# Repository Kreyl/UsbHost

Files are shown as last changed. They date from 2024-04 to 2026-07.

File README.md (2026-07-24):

# UsbHost
PCB with MCU &amp; CC1101, with USB connector

This project is for manupulating Ostranna devices from PC using radio
This branch is for Magic Stick project. There are two devices in system, host and wand https://github.com/Kreyl/MagicStick.
Wand sends raw data from IMU to host and host may send commands to wand.

Protocol descrideb here (in Russian) https://docs.google.com/document/d/1Enq7OxXN71MnZqI4T44DpILLiYlTNmURxSFmcvyZTgg/edit
List of commands in Russian https://docs.google.com/document/d/1xTNT9nXQbrqk0kijIyspimRIQRoJOtMbkZyYuiGS3eA/edit#heading=h.siqy2t4hsq6f
USB2Radio devices displays itself as virtual COM-port, you may user Terminal app to send commands or send commands from your code to serial port object. 

Archived branches are available here https://github.com/Kreyl/UsbHost/tags

We also have python module to work with USB2Radio  (in python folder). 

<details>
  <summary>Commands list:</summary> 

*get_port_list() function returns list of available comports as ['COM3', 'COM5', 'COM20' ...];

*get_device_port function returns first found port with Ostranna device (answer 'Ack 0' to 'Ping\r\n') as 'COM4';

*get_all_device_ports() returns list of comports with Ostranna devices connected 
                        (answer 'Ack 0' to 'Ping\r\n') as ['COM4', ...];

*open_port(port_id: str) takes comport as str parameter (open_port('COM4') and returns open port or None;

*send command(ser, command, parameters) send command with parameters to ser port, returns send status
              ("ok", "Bad data", "Unknown command" or "No device port") ;

*send query(ser, command, parameters) send query with parameters to ser port and returns answer;

*close_port(ser) gets result of open_port(port_id) as parameter and closes it .
</details>

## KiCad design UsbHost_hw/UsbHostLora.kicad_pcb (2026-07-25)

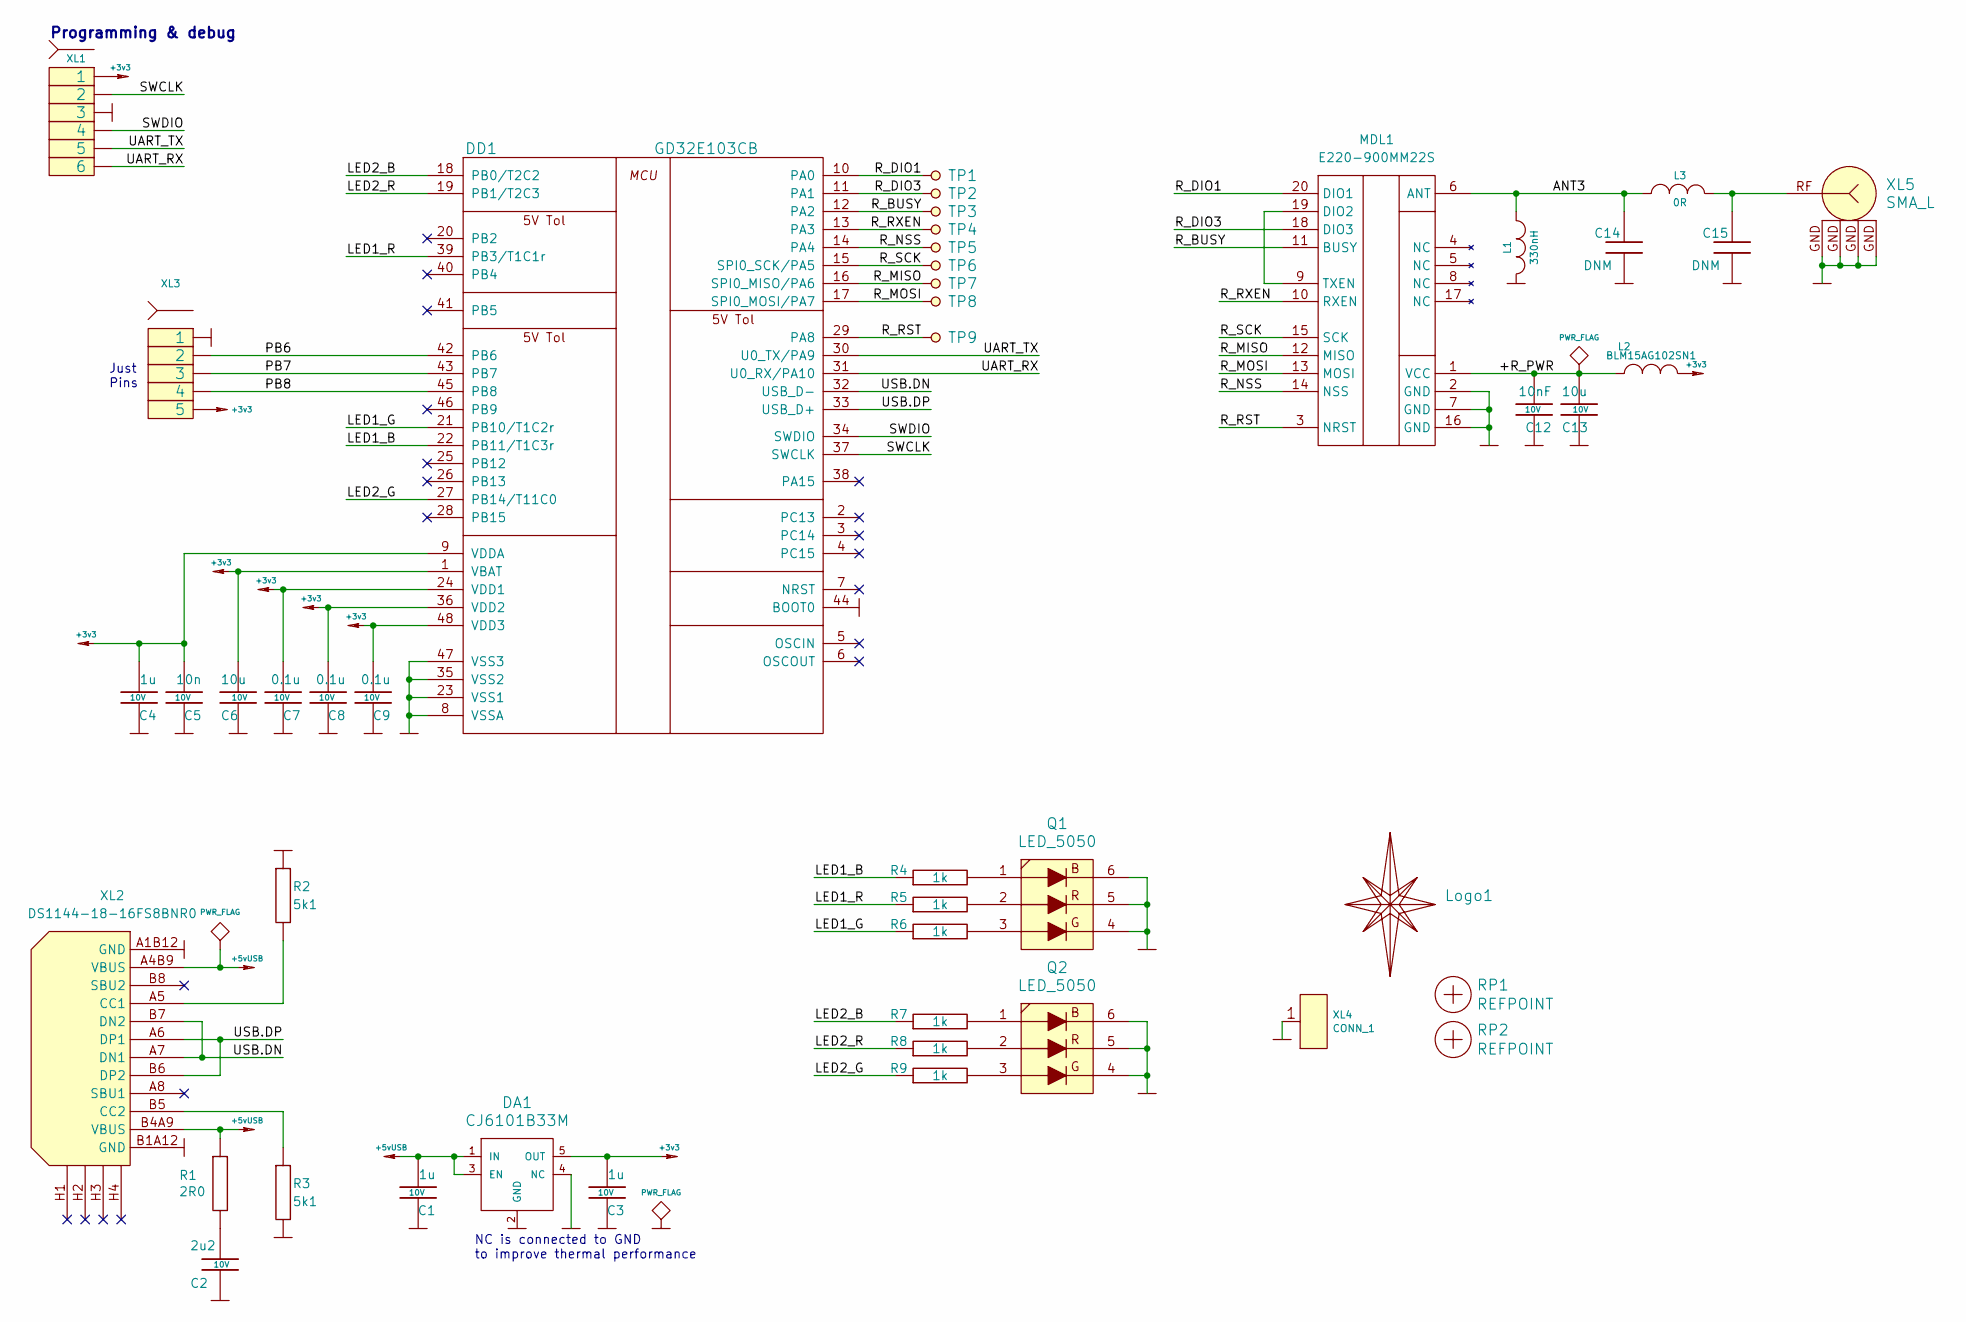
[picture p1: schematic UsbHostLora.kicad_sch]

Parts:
C1, C3, C4: 1u; CAP_0603_Silks; Tolerance 20%; Voltage 10V
C2: 2u2; CAP_0603_Silks; Tolerance 20%; Voltage 10V
C5: 10n; CAP_0603_Silks; Tolerance 20%; Voltage 10V
C6, C13: 10u; CAP_0603_Silks; Tolerance 20%; Voltage 10V
C7, C8, C9: 0.1u; CAP_0603_Silks; Tolerance 20%; Voltage 10V
C12: 10nF; CAP_0603_Silks; Tolerance 20%; Voltage 10V
C14, C15: DNM; CAP_0402_Silks; Tolerance 20%; Voltage 10V
DA1: CJ6101B33M; SOT23-5
DD1: GD32E103CB; LQFP48
L1: 330nH; IND_0402; Tolerance 20%
L2: BLM15AG102SN1; IND_0402; Tolerance 20%
L3: 0R; IND_0402; Tolerance 20%
Logo1: Logo; Ostranna_12d7_10d1
MDL1: E220-900MM22S
Q1, Q2: LED_5050
R1: 2R0; RES_0603_RefFab; Tolerance 1%
R2, R3: 5k1; RES_0603_RefFab; Tolerance 1%
R4, R5, R6, R7, R8, R9: 1k; RES_0603_RefFab; Tolerance 1%
RP1, RP2: REFPOINT; REF_POINT_1MM
TP1, TP2, TP3, TP4, TP5, TP6, TP7, TP8, TP9: TESTPOINT; TESTPOINT_1MM
XL1: SOCKET_6; PLS-6_LOCK
XL2: DS1144-18-16FS8BNR0; USBC_10PF-074_1
XL3: SOCKET_5; PLS-5
XL4: CONN_1; OSCIL_GND
XL5: SMA_L; SMA_R

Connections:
+3v3: C3.1, C4.1, C5.1, C6.1, C7.1, C8.1, C9.1, DA1.5 (OUT), DD1.1 (VBAT), DD1.9 (VDDA), DD1.24 (VDD1), DD1.36 (VDD2), DD1.48 (VDD3), L2.1, XL1.1, XL3.5
+5vUSB: C1.1, DA1.1 (IN), DA1.3 (EN), R1.1, XL2.A4B9 (VBUS), XL2.B4A9 (VBUS)
/+R_PWR: C12.1, C13.1, L2.2, MDL1.1 (VCC)
/ANT3: C14.1, L1.2, L3.2, MDL1.6 (ANT)
/LED1_B: DD1.22 (PB11/T1C3r), R4.1
/LED1_G: DD1.21 (PB10/T1C2r), R6.1
/LED1_R: DD1.39 (PB3/T1C1r), R5.1
/LED2_B: DD1.18 (PB0/T2C2), R7.1
/LED2_G: DD1.27 (PB14/T11C0), R9.1
/LED2_R: DD1.19 (PB1/T2C3), R8.1
/PB6: DD1.42 (PB6), XL3.2
/PB7: DD1.43 (PB7), XL3.3
/PB8: DD1.45 (PB8), XL3.4
/R_BUSY: DD1.12 (PA2), MDL1.11 (BUSY), TP3.1
/R_DIO1: DD1.10 (PA0), MDL1.20 (DIO1), TP1.1
/R_DIO3: DD1.11 (PA1), MDL1.18 (DIO3), TP2.1
/R_MISO: DD1.16 (SPI0_MISO/PA6), MDL1.12 (MISO), TP7.1
/R_MOSI: DD1.17 (SPI0_MOSI/PA7), MDL1.13 (MOSI), TP8.1
/R_NSS: DD1.14 (PA4), MDL1.14 (NSS), TP5.1
/R_RST: DD1.29 (PA8), MDL1.3 (NRST), TP9.1
/R_RXEN: DD1.13 (PA3), MDL1.10 (RXEN), TP4.1
/R_SCK: DD1.15 (SPI0_SCK/PA5), MDL1.15 (SCK), TP6.1
/SWCLK: DD1.37 (SWCLK), XL1.2
/SWDIO: DD1.34 (SWDIO), XL1.4
/UART_RX: DD1.31 (U0_RX/PA10), XL1.6
/UART_TX: DD1.30 (U0_TX/PA9), XL1.5
/USB.DN: DD1.32 (USB_D-), XL2.A7 (DN1), XL2.B7 (DN2)
/USB.DP: DD1.33 (USB_D+), XL2.A6 (DP1), XL2.B6 (DP2)
GND: C1.2, C2.2, C3.2, C4.2, C5.2, C6.2, C7.2, C8.2, C9.2, C12.2, C13.2, C14.2, C15.2, DA1.2 (GND), DA1.4 (NC), DD1.8 (VSSA), DD1.23 (VSS1), DD1.35 (VSS2), DD1.44 (BOOT0), DD1.47 (VSS3), L1.1, MDL1.2 (GND), MDL1.7 (GND), MDL1.16 (GND), Q1.4 (B), Q1.5 (G), Q1.6, Q2.4 (B), Q2.5 (G), Q2.6, R2.1, R3.2, XL1.3, XL2.A1B12 (GND), XL2.B1A12 (GND), XL3.1, XL4.1 (P1_1), XL5.GND
unnamed: C2.1, R1.2
unnamed: C15.1, L3.1, XL5.RF
unnamed: MDL1.9 (TXEN), MDL1.19 (DIO2)
unnamed: Q1.1, R4.2
unnamed: Q1.2, R5.2
unnamed: Q1.3, R6.2
unnamed: Q2.1, R7.2
unnamed: Q2.2, R8.2
unnamed: Q2.3, R9.2
unnamed: R2.2, XL2.A5 (CC1)
unnamed: R3.1, XL2.B5 (CC2)

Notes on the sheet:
Just Pins
NC is connected to GND to improve thermal performance
Programming & debug

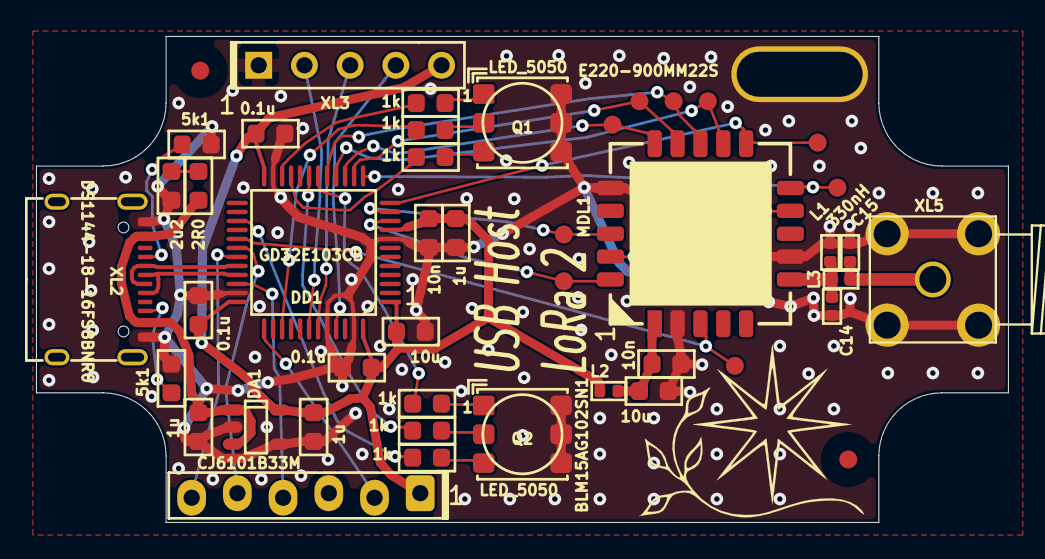
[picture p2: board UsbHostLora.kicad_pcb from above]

Board: 2 copper layers, 54.0 x 27.0 mm, 47 parts (0 on the bottom side), 40 nets.

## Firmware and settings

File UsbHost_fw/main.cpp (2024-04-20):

#include "uart.h"
#include "ch.h"
#include "hal.h"
#include "MsgQ.h"
#include "shell.h"
#include "kl_lib.h"
#include "Sequences.h"
#include "led.h"
#include "color.h"
#include "usb_cdc.h"
#include "Lora.h"

#if 1 // ======================== Variables and defines ========================
// Forever
EvtMsgQ_t<EvtMsg_t, MAIN_EVT_Q_LEN> EvtQMain;
static const UartParams_t CmdUartParams(115200, CMD_UART_PARAMS);
CmdUart_t Uart{CmdUartParams};
void OnCmd(Shell_t *PShell);
void ITask();

LedRGB_t Led { LED_R_PIN, LED_G_PIN, LED_B_PIN, 1000 };

// [2; 20]
#define TX_PWR_dBm      11
// bwLora125kHz, bwLora250kHz, bwLora500kHz
#define LORA_BW         bwLora250kHz
// sprfact64chipsPersym, sprfact128chipsPersym, sprfact256chipsPersym, sprfact512chipsPersym,
// sprfact1024chipsPersym, sprfact2048chipsPersym, sprfact4096chipsPersym
#define LORA_SPREADRFCT sprfact1024chipsPersym
// coderate4s5, coderate4s6, coderate4s7, coderate4s8
#define LORA_CODERATE   coderate4s8
#endif


void main(void) {
    // ==== Init Clock system ====
    Clk.EnablePrefetch();
    Clk.SetupFlashLatency(48000000);
    Clk.SetupBusDividers(ahbDiv1, apbDiv1);
    Clk.SwitchTo(csHSI48);
    Clk.UpdateFreqValues();

    // === Init OS ===
    halInit();
    chSysInit();
    EvtQMain.Init();

    // ==== Init hardware ====
    Uart.Init();
    Printf("\r%S %S\r", APP_NAME, XSTRINGIFY(BUILD_TIME));
    Clk.PrintFreqs();

    Led.Init();
    Led.StartOrRestart(lsqStart);

    Lora.Init();
    Lora.SetChannel(868000000);
    Lora.SetupRxConfigLora(LORA_BW, LORA_SPREADRFCT, LORA_CODERATE, hdrmodeExplicit, 64);
    Lora.SetupTxConfigLora(TX_PWR_dBm, LORA_BW, LORA_SPREADRFCT, LORA_CODERATE, hdrmodeExplicit);

    UsbCDC.Init();
    Clk.EnableCRS();
    Clk.SelectUSBClock_HSI48();
    UsbCDC.Connect();

    ITask(); // Main cycle
}

__noreturn
void ITask() {
    while(true) {
        EvtMsg_t Msg = EvtQMain.Fetch(TIME_INFINITE);
        switch(Msg.ID) {
            case evtIdShellCmdRcvd:
                while(((CmdUart_t*)Msg.Ptr)->TryParseRxBuff() == retvOk) OnCmd((Shell_t*)((CmdUart_t*)Msg.Ptr));
                break;

#if 1       // ======= USB =======
            case evtIdUsbCmdRcvd:
                Led.StartOrRestart(lsqUSBCmd);
                OnCmd((Shell_t*)&UsbCDC);
                UsbCDC.SignalCmdProcessed();
                break;

            case evtIdUsbConnect:
                Printf("USB connect\r");
                Clk.EnableCRS();
                Clk.SelectUSBClock_HSI48();
                UsbCDC.Connect();
                break;

            case evtIdUsbDisconnect: {
                UsbCDC.Disconnect();
                Clk.DisableCRS();
                Printf("USB disconnect\r");
            } break;

            case evtIdUsbReady:
                Printf("USB ready\r");
                Led.StartOrRestart(lsqUsbReady);
                break;
#endif

            default: break;
        } // switch
    } // while true
}

const char* strBW[3] = {"125kHz", "250kHz", "500kHz"};
SXLoraBW_t bw[3] = {bwLora125kHz, bwLora250kHz, bwLora500kHz};


const char* strSF[7] = {
        "64cps", "128cps", "256cps", "512cps", "1024cps", "2048cps", "4096cps"
};
SXSpreadingFactor_t sf[7] = {sprfact64chipsPersym, sprfact128chipsPersym, sprfact256chipsPersym,
        sprfact512chipsPersym, sprfact1024chipsPersym, sprfact2048chipsPersym, sprfact4096chipsPersym
};

const char* strCR[4] = {
        "4s5", "4s6", "4s7", "4s8"
};

SXCodingRate_t CR[4] = {
        coderate4s5, coderate4s6, coderate4s7, coderate4s8
};

#if 1 // =========================== Pkt_t =====================================
#pragma pack(push, 1)
union rPkt_t {
    struct {
        uint32_t reply;
        uint32_t salt_reply;
    };
    struct {
        uint8_t cmd;
        union {
            struct { int16_t grif, slyze, rave, huff; };
            struct {
                uint16_t year;
                uint8_t month, day, hours, minutes;
            };
        };
    };
};
#pragma pack(pop)

static const uint8_t kcmd_set_shown = 1;
static const uint8_t kcmd_set_hidden = 0;
static const uint8_t kcmd_set_time = 7;

#define RPKT_SALT   0xF1170511 // Fly to sly
#define RPKT_LEN    sizeof(rPkt_t)
rPkt_t rpkt;
static uint8_t rxbuf[LORA_FIFO_SZ];
#endif

void TryToTxRpkt(Shell_t *PShell) {
    for(uint8_t i=0; i<4; i++) { // Try several times
        Lora.SetupTxConfigLora(TX_PWR_dBm, LORA_BW, LORA_SPREADRFCT, LORA_CODERATE, hdrmodeExplicit);
        Lora.TransmitByLora((uint8_t*)&rpkt, RPKT_LEN);
        uint8_t len = LORA_FIFO_SZ;
        Lora.SetupRxConfigLora(LORA_BW, LORA_SPREADRFCT, LORA_CODERATE, hdrmodeExplicit, 64);
        uint8_t Rslt = Lora.ReceiveByLora(rxbuf, &len, 270);
        rPkt_t *pkt_rx = (rPkt_t*)rxbuf;
        if(Rslt == retvOk and len == RPKT_LEN and pkt_rx->salt_reply == RPKT_SALT) {
            PShell->Print("Result: Ok  SNR: %d; RSSI: %d\r\n", Lora.RxParams.SNR, Lora.RxParams.RSSI);
            return;
//                PShell->Print("Rply: %X; SNR: %d; RSSI: %d\r", PktRx->Reply, Lora.RxParams.SNR, Lora.RxParams.RSSI);
        }
        else if(Rslt == retvCRCError) PShell->Print("CRCErr\r\n");
        else PShell->Print("%u: Timeout\r\n", i);
        chThdSleepMilliseconds(180);
    } // for
    PShell->Print("Result: Fail\r\n");
}


#if 1 // ======================= Command processing ============================
void OnCmd(Shell_t *PShell) {
    Cmd_t *PCmd = &PShell->Cmd;
//    Printf("%S\r", PCmd->Name);
    // Handle command
    if(PCmd->NameIs("Ping")) PShell->Ok();
    else if(PCmd->NameIs("Version")) PShell->Print("Version: %S %S\r", APP_NAME, XSTRINGIFY(BUILD_TIME));
    else if(PCmd->NameIs("mem")) PrintMemoryInfo();

    else if(PCmd->NameIs("TX")) {
        uint8_t Pwr, BWIndx, SFIndx, CRIndx;
        uint8_t FBuf[LORA_FIFO_SZ];
        if(PCmd->GetParams<uint8_t>(4, &Pwr, &BWIndx, &SFIndx, &CRIndx) == retvOk) {
            Lora.SetupTxConfigLora(Pwr, bw[BWIndx], sf[SFIndx], CR[CRIndx], hdrmodeExplicit);
            uint8_t b, Cnt=0;
            while(PCmd->GetNext<uint8_t>(&b) == retvOk) {
                FBuf[Cnt++] = b;
                if(Cnt == LORA_FIFO_SZ) break;
            }
            if(Cnt) {
                PShell->Print("Pwr=%u; Len=%u; %S; %S; %S; Dur=%u\r\n",
                        Pwr, Cnt, strBW[BWIndx], strSF[SFIndx], strCR[CRIndx],
                        Lora.TransmitByLora(FBuf, Cnt));
            }
            else PShell->CmdError();
        }
        else PShell->CmdError();
    }

    else if(PCmd->NameIs("Set")) {
        int32_t arr[5];
        if(PCmd->GetArray(arr, 5) == retvOk) {
            rpkt.grif  = arr[0];
            rpkt.slyze = arr[1];
            rpkt.rave  = arr[2];
            rpkt.huff  = arr[3];
            rpkt.cmd = arr[4]? kcmd_set_shown : kcmd_set_hidden;
            TryToTxRpkt(PShell);
        }
        else PShell->BadParam();
    }

    else if(PCmd->NameIs("SetTime")) {
        uint16_t arr[5];
        if(PCmd->GetArray(arr, 5) == retvOk) {
            rpkt.cmd = kcmd_set_time;
            rpkt.year    = arr[0];
            rpkt.month   = arr[1];
            rpkt.day     = arr[2];
            rpkt.hours   = arr[3];
            rpkt.minutes = arr[4];
            TryToTxRpkt(PShell);
        }
        else PShell->BadParam();
    }

    // ==== Lora params ====
    else if(PCmd->NameIs("SetParams")) {
        uint8_t Pwr, BWIndx, SFIndx, CRIndx;
        if(PCmd->GetParams<uint8_t>(4, &Pwr, &BWIndx, &SFIndx, &CRIndx) == retvOk) {
            Lora.SetupTxConfigLora(Pwr, bw[BWIndx], sf[SFIndx], CR[CRIndx], hdrmodeExplicit);
            Lora.SetupRxConfigLora(bw[BWIndx], sf[SFIndx], CR[CRIndx], hdrmodeExplicit, 64);
            PShell->Print("Pwr=%u; %S; %S; %S\r\n", Pwr, strBW[BWIndx], strSF[SFIndx], strCR[CRIndx]);
        }
        else PShell->CmdError();
    }

    else if(PCmd->NameIs("Regs")) Lora.PrintRegs();
    else if(PCmd->NameIs("Sta")) Lora.PrintState();

    else if(PCmd->NameIs("help")) {
        PShell->Print( "SetTime <Year> <Month> <Day> <H> <M>\r"
                "Set <Grif> <Slyze> <Rave> <Huff> <show_points> - set points\r"
        );
    }

    else PShell->CmdUnknown();
}
#endif

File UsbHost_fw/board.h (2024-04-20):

/*
 * board.h
 *
 *  Created on: 01.02.2017
 *      Author: Kreyl
 */

#ifndef BOARD_H__
#define BOARD_H__

// ==== General ====
#define BOARD_NAME          "UsbHostLora"
#define APP_NAME            "UsbHostFlasks"

// MCU type as defined in the ST header.
#define STM32F072xB     // no matter, 8 or B

// Freq of external crystal if any. Leave it here even if not used.
#define CRYSTAL_FREQ_HZ         12000000

// Ch timer
#define STM32_ST_IRQ_PRIORITY   2
#define STM32_ST_USE_TIMER      2
#define SYS_TIM_CLK             (Clk.APBFreqHz)

#define SIMPLESENSORS_ENABLED   FALSE
#define BUTTONS_ENABLED         FALSE
#define ADC_REQUIRED            FALSE
#define I2C1_ENABLED            FALSE
#define I2C_USE_SEMAPHORE       FALSE

#if 1 // ========================== GPIO =======================================
// PortMinTim_t: GPIO, Pin, Tim, TimChnl, invInverted, omPushPull, TopValue

// UART
#define UART_GPIO       GPIOA
#define UART_TX_PIN     9
#define UART_RX_PIN     10

// USB
#define USB_DM          GPIOA, 11
#define USB_DP          GPIOA, 12

// LED
#define LED_R_PIN       { GPIOC, 6, TIM3, 1, invNotInverted, omPushPull, 255 }
#define LED_G_PIN       { GPIOC, 8, TIM3, 2, invNotInverted, omPushPull, 255 }
#define LED_B_PIN       { GPIOC, 7, TIM3, 3, invNotInverted, omPushPull, 255 }

// ==== Lora ====
#define SX_SPI          SPI1
#define SX_SCK          GPIOA,  5, omPushPull, pudNone, AF0
#define SX_MISO         GPIOA,  6, omPushPull, pudNone, AF0
#define SX_MOSI         GPIOA,  7, omPushPull, pudNone, AF0
#define SX_NSS          GPIOA, 4
#define SX_NRESET       GPIOC, 3
#define SX_DIO0_GPIO    GPIOA
#define SX_DIO0_PIN     0
#define SX_DIO1_GPIO    GPIOA
#define SX_DIO1_PIN     1
#define SX_DIO2_GPIO    GPIOA
#define SX_DIO2_PIN     2
#define SX_DIO3_GPIO    GPIOA
#define SX_DIO3_PIN     3
#define SX_DIO4_GPIO    GPIOC
#define SX_DIO4_PIN     4
#define SX_DIO5_GPIO    GPIOC
#define SX_DIO5_PIN     5

#endif // GPIO

#if 1 // ========================== USB ========================================
#define USBDrv          USBD1   // USB driver to use

// CRS
#define CRS_PRESCALER   RCC_CRS_SYNC_DIV1
#define CRS_SOURCE      RCC_CRS_SYNC_SOURCE_USB
#define CRS_POLARITY    RCC_CRS_SYNC_POLARITY_RISING
#define CRS_RELOAD_VAL  ((48000000 / 1000) - 1) // Ftarget / Fsync - 1
#define CRS_ERROR_LIMIT 34
#define HSI48_CALIBRATN 32
#endif

#if 1 // =========================== DMA =======================================
#define STM32_DMA_REQUIRED  TRUE
// ==== Uart ====
#define UART_DMA_TX_MODE(Chnl) (STM32_DMA_CR_CHSEL(Chnl) | DMA_PRIORITY_LOW | STM32_DMA_CR_MSIZE_BYTE | STM32_DMA_CR_PSIZE_BYTE | STM32_DMA_CR_MINC | STM32_DMA_CR_DIR_M2P | STM32_DMA_CR_TCIE)
#define UART_DMA_RX_MODE(Chnl) (STM32_DMA_CR_CHSEL(Chnl) | DMA_PRIORITY_MEDIUM | STM32_DMA_CR_MSIZE_BYTE | STM32_DMA_CR_PSIZE_BYTE | STM32_DMA_CR_MINC | STM32_DMA_CR_DIR_P2M | STM32_DMA_CR_CIRC)
#define UART_DMA_TX     STM32_DMA_STREAM_ID(1, 2)
#define UART_DMA_RX     STM32_DMA_STREAM_ID(1, 3)
#define UART_DMA_CHNL   0   // Dummy

#endif // DMA

#if 1 // ========================== USART ======================================
#define PRINTF_FLOAT_EN FALSE
#define UART_TXBUF_SZ   2048
#define UART_RXBUF_SZ   1024
#define CMD_BUF_SZ      256

#define CMD_UART        USART1


#define CMD_UART_PARAMS \
    CMD_UART, UART_GPIO, UART_TX_PIN, UART_GPIO, UART_RX_PIN, \
    UART_DMA_TX, UART_DMA_RX, UART_DMA_TX_MODE(UART_DMA_CHNL), UART_DMA_RX_MODE(UART_DMA_CHNL), \
    uartclkHSI // independent clock

#endif

#endif //BOARD_H__

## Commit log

2016-02-08 + UsbHost hw
    [UsbHost.kicad_pcb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]
2016-02-08 * switch to 16.1.3 + USB works ok
2016-02-29 + UsbHost2 hw
    [UsbHost.kicad_pcb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]
2016-03-04 + USB CDC works + CC replies, radio not tuned + LED works
    [UsbHost.kicad_pcb]
2016-03-05 * Antenna matched: 2.7pF, 5.6nH, 0pF
    [UsbHost.sch]
2019-05-27 baudrate in python module fixed
    [Usbhost.py]
2019-06-20 fixed python module for no comport logic
    [Usbhost.py]
2021-05-12 Sch in progress
    [UsbHost.kicad_pcb, UsbHost.sch, UsbHostLora.kicad_pcb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]
2021-05-12 sch done
    [UsbHostLora.kicad_sch]
2021-05-13 Routing done
    [UsbHostLora.kicad_pcb, UsbHostLora.kicad_sch]
2021-05-13 + GERBERs
    [UsbHostLora.kicad_pcb, UsbHostLora.kicad_sch]
2021-07-12 + Antenna tuned
    [UsbHostLora.kicad_sch]
2021-07-17 * Switch to CubeIDE + USB works
2024-04-20 Switch to Eclipse + time control
2024-04-20 Switch from "hidden" to "shown" logic
2026-07-25 Sent to factory
    [UsbHostLora.kicad_pcb, UsbHostLora.kicad_sch]
